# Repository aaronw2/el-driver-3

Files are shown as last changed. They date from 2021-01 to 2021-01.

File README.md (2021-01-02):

# el-driver-3
EL Wire Driver using Microchip MIC4832

Copyright (C) 2021 Aaron Williams

The enable pin is active high and requires 3V up to VCC.  It is pulled
low by a 1M resistor.  This board is optimized for 100Hz and 3 square inches
of EL panel.

VCC is 3-5V

Note that C2 must be rated for 250VDC or higher.

See page 11 of the MIC4832 datasheet at:
https://ww1.microchip.com/downloads/en/DeviceDoc/MIC4832-Low-Noise-220VPP-EL-Driver-DS20006163A.pdf

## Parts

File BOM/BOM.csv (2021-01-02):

Refs | Value | Footprint | Quantity | DESC | MFR | MPN | SPR | SPN | SPURL
C3 | 10uF | Capacitor_SMD:C_0603_1608Metric | 1 | - | Murata Electronics | GRT188R61E106ME13D | Digikey | 490-12323-1-ND | -
C1 | 2.2uF | Capacitor_SMD:C_0603_1608Metric | 1 | - | Yageo | CC0603MRY5V7BB225 | Digikey | 311-3415-1-ND | -
C2 | 0.015uF 250V | Capacitor_SMD:C_1206_3216Metric | 1 | Multilayer Ceramic Capacitors MLCC - SMD/SMT 250V 0.01uF C0G 1206 5% AECQ200 | KEMET | C1206C153KARECAUTO | Digikey | 399-17899-1-ND | https://www.digikey.com/en/products/detail/kemet/C1206C153KARECAUTO/8640493
J1 | Conn_01x02 | Connector_JST:JST_XH_B2B-XH-A_1x02_P2.50mm_Vertical | 1 | Connector Header Through Hole 3 position 0.098" (2.50mm) | JST Sales America Inc. | B2B-XH-A-GU | Digikey | 455-2946-ND | https://www.digikey.com/en/products/detail/jst-sales-america-inc/B2B-XH-A-GU/2043065
J2 | Conn_01x03 | Connector_JST:JST_XH_B3B-XH-A_1x03_P2.50mm_Vertical | 1 | Connector Header Through Hole 3 position 0.098" (2.50mm) | JST Sales America Inc. | B3B-XH-AM(LF)(SN) | Digikey | 455-2231-ND | https://www.digikey.com/en/products/detail/jst-sales-america-inc/B3B-XH-AM-LF-SN/1651029
L1 | 220uH | Inductor_SMD:L_Bourns_SRN8040TA | 1 | 220µH Semi-Shielded Wirewound Inductor 850mA 610mOhm Nonstandard | Bourns Inc. | SRN8040TA-221M | Digikey | SRN8040TA-221MCT-ND | https://www.digikey.com/en/products/detail/bourns-inc/SRN8040TA-221M/6155141
U1 | MIC4832 | Package_DFN_QFN:DFN-8-1EP_3x3mm_P0.5mm_EP1.66x2.38mm | 1 | EL Lamp Driver Controller 60Hz ~ 1kHz No 8-MSOP | Microchip Technology | MIC4832YMM | Digikey | 998-MIC4832YMM | https://www.digikey.com/en/products/detail/microchip-technology/MIC4832YMM/1815444
D1 | BAS20 | Package_TO_SOT_SMD:SOT-23 | 1 | Diode Standard 200V 200mA Surface Mount SOT-23-3 (TO-236) | ON Semiconductor | BAS20 | Digikey | BAS20FSCT-ND | https://www.digikey.com/en/products/detail/on-semiconductor/BAS20/976312
Q1;Q2 | BSS138 | Package_TO_SOT_SMD:SOT-23 | 2 | - | ON Semiconductor | BSS138 | Digikey | BSS138CT-ND | -
R1;R2 | 1M | Resistor_SMD:R_0603_1608Metric | 2 | 1 MOhms ±1% 0.1W, 1/10W Chip Resistor 0603 (1608 Metric) Automotive AEC-Q200 Thick Film | Stackpole Electronics Inc | RMCF0603FT1M00 | Digikey | RMCF0603FT1M00CT-ND | https://www.digikey.com/en/products/detail/stackpole-electronics-inc/RMCF0603FT1M00/1761036
R4 | 2.8M | Resistor_SMD:R_0603_1608Metric | 1 | 2.8 MOhms ±1% 0.1W, 1/10W Chip Resistor 0603 (1608 Metric) Automotive AEC-Q200 Thick Film | Vishay Dale | CRCW06032M80FKEA | Digikey | 541-2.80MHCT-ND | https://www.digikey.com/en/products/detail/CRCW06032M80FKEA/541-2.80MHCT-ND/1180201
R3 | 309K | Resistor_SMD:R_0603_1608Metric | 1 | RES SMD 309K OHM 1% 1/10W 0603 | Panasonic Electronic Components | ERJ-3EKF3093V | Digikey | P309KHCT-ND | https://www.digikey.com/en/products/detail/panasonic-electronic-components/ERJ-3EKF3093V/196288
R5 | 4.7K | Resistor_SMD:R_0603_1608Metric | 1 | - | Yageo | RC0603FR-074K7L | Digikey | 311-4.70KHRCT-ND | -

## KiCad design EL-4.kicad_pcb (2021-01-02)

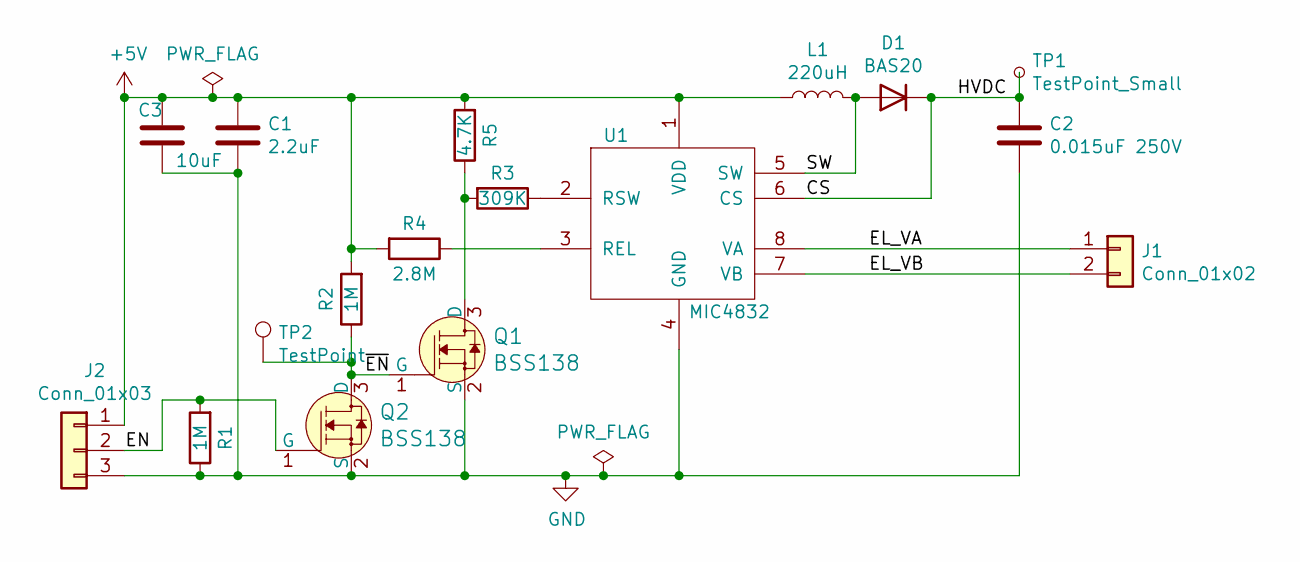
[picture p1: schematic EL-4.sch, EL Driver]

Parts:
C1: 2.2uF; C_0603_1608Metric; MPN CC0603MRY5V7BB225
C2: 0.015uF 250V; C_1206_3216Metric; MPN C1206C153KARECAUTO
C3: 10uF; C_0603_1608Metric; MPN GRT188R61E106ME13D
D1: BAS20; SOT-23; MPN BAS20
J1: Conn_01x02; JST_XH_B2B-XH-A_1x02_P2.50mm_Vertical; MPN B2B-XH-A-GU
J2: Conn_01x03; JST_XH_B3B-XH-A_1x03_P2.50mm_Vertical; MPN B3B-XH-AM(LF)(SN)
L1: 220uH; L_Bourns_SRN8040TA; MPN SRN8040TA-221M
Q1, Q2: BSS138; SOT-23; MPN BSS138; Digi-Key_PN BSS138CT-ND
R1, R2: 1M; R_0603_1608Metric; MPN RMCF0603FT1M00
R3: 309K; R_0603_1608Metric; MPN ERJ-3EKF3093V
R4: 2.8M; R_0603_1608Metric; MPN CRCW06032M80FKEA
R5: 4.7K; R_0603_1608Metric; MPN RC0603FR-074K7L
TP1: TestPoint_Small; TestPoint_Pad_D1.0mm
TP2: TestPoint; TestPoint_Pad_D1.0mm
U1: MIC4832; DFN-8-1EP_3x3mm_P0.5mm_EP1.66x2.38mm; MPN MIC4832YMM

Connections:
+5V: C1.1, C3.1, J2.1, L1.1, R2.2, R4.2, R5.2, U1.1 (VDD)
/CS: C2.1, D1.3 (K), TP1.1, U1.6 (CS)
/EK_VB: J1.2, U1.7 (VB)
/EL_VA: J1.1, U1.8 (VA)
/EN: J2.2, Q2.1 (G), R1.2
/SW: D1.1 (A), L1.2, U1.5 (SW)
/~EN: Q1.1 (G), Q2.3 (D), R2.1, TP2.1
GND: C1.2, C2.2, C3.2, J2.3, Q1.2 (S), Q2.2 (S), R1.1, U1.4 (GND)
unnamed: Q1.3 (D), R3.2, R5.1
unnamed: R3.1, U1.2 (RSW)
unnamed: R4.1, U1.3 (REL)

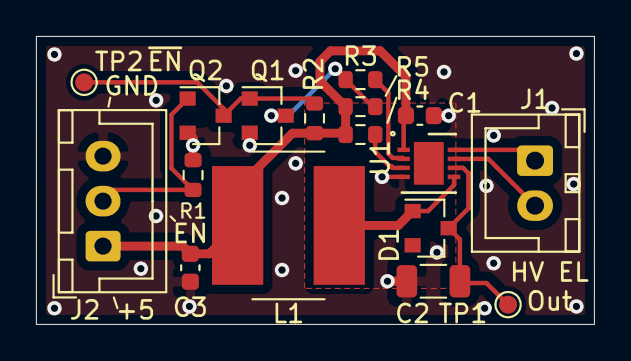
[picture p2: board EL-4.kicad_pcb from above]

Board: 2 copper layers, 31.0 x 16.0 mm, 17 parts (0 on the bottom side), 11 nets.

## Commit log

2021-01-02 Initial checkin of version 0.9.
    [EL-4.kicad_pcb, EL-4.sch]
2021-01-02 Version 1.0.
    Changed enable method to pull RSW R3 to ground.
    Changed R3, R4, R5 and C2 for 100Hz operation for 3 square inches.
    Added input filter cap.
    Also added BOM.
    [BOM.csv, EL-4.kicad_pcb, EL-4.sch]

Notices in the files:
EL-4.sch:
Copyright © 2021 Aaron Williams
